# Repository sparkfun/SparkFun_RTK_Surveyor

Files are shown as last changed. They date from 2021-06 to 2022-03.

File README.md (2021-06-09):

SparkFun RTK Surveyor - Hardware
===========================================================

SparkFun RTK Surveyor (https://www.sparkfun.com/products/17369)

[*SparkFun RTK Surveyor (SPX-17369)*](https://www.sparkfun.com/products/17369)

The SparkFun RTK Surveyor is an easy to use GNSS receiver for centimeter-level positioning. Perfect for surveying, this preprogrammed device can also be used for autonomous driving, navigation, asset tracking and any other application where there is a clear view of the sky. The RTK Surveyor can also be used as a base station. With the flick of a switch, two RTK Surveyors can be used to create an RTK system capable of 14mm horizontal positional accuracy. The built-in Bluetooth connection via an ESP32 WROOM enables the user to use the RTK Surveyor with their choice of GIS application on a phone or tablet. The built in battery allows field use for up to four hours and is compatible with common USB battery banks.

This repo houses the hardware for the product including the PCB design, enclosure, and graphic overlay. The firmware for the RTK Surveyor (and other SparkFun RTK products) can be found [here](https://github.com/sparkfun/SparkFun_RTK_Firmware).

SparkFun labored with love to create this product. Feel like supporting open source hardware? 
[Buy a product](https://www.sparkfun.com/products/17369) from SparkFun!

Repository Contents
-------------------

* **/Documents** - Documentation on hardware and 3D files for the enclosure
* **/Enclosure** - gcode for enclosure milling
* **/Graphics** - Bitmaps for display (not currently implmented)
* **/Hardware** - Eagle files

Documentation
--------------

* **[Hookup Guide](https://learn.sparkfun.com/tutorials/sparkfun-rtk-surveyor-hookup-guide)** - Hookup guide for the SparkFun RTK Surveyor.

License Information
-------------------

This product is _**open source**_!

Various bits of the code have different licenses applied. Anything SparkFun wrote is beerware; if you see me (or any other SparkFun employee) at the local, and you've found our code helpful, please buy us a round!

Please use, reuse, and modify these files as you see fit. Please maintain attribution to SparkFun Electronics and release anything derivative under the same license.

Distributed as-is; no warranty is given.

- Your friends at SparkFun.

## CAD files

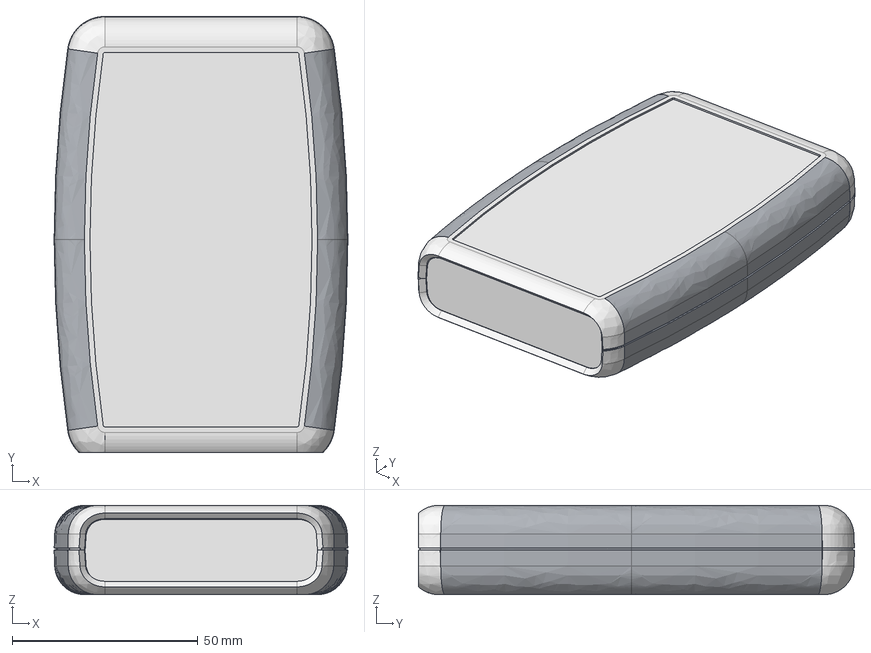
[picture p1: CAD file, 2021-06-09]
Documents/1553B-1.stp
79.0 x 117.2 x 24.0 mm
1553B TOP
1553B BOTTOM
1553B Front Panel
1553B TOP GRIP
1553B BOTTOM GRIP
1553B PCB

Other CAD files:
Documents/1553B-1.igs

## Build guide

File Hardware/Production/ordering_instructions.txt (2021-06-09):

panel size, 220x138mm
PCB thickness, 1.6mm
number of layers, 4
soldermask color, Red
silkscreen color, White
oz copper, 1oz
finish, HASL lead free
stencils, none
pcs per panel, 3
min trace width, 0.1778mm / 0.0070in
min drill size, 0.3048mm / 0.0120in
filename to layer stackup 1/2/3/4: GTL, GL2, GL3, GBL

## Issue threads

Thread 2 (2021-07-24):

RTK Surveor does not charge Lipo battery

artosaurus, 2021-07-24:
### RTK Surveor does not charge Lipo battery

RTK Surveyor does not charge its Lipo battery when connected to USB with wall adapter. The LED is totally off. When I switch power on the LED is red. I replaced new Lipo-battery and this does not help. It is possible to charge he battery of Surveyor using Turnigy charger so the battery is not malfunctioning.
To your information, I have RTK Surveyor and also RTK Express. I am using Surveoyr as Base and Express as Rover.
I bought Surveyor about a year ago and did not use it at all because I noticed that I need a second unit. Therefore, I bought RTK express during summer 2021 and now I started to use these together and noticed this battery cahrger problem in Surveyor.
I tested Surveyor using the battery from RTK Express but the same problem exist - the LED is off and does not charge the battery. My RTK Surveyor is damaged for some reason. I can use it only when it is connected to an external USB power bank.

### Your workbench
SparkFun RTK Surveyor v1.3-Jun  7 2021.
Bluetooth is working OK.
NTRIP is coming via radio or alternatively website RT2GO and Bluetooth.
Everything is powered by external USB because battery is empty. Surveyour does not charge the battery anymore. The LED is totally off when main power of Surveyor is off and USB is connected.

### Steps to reproduce
Tell us how to reproduce this issue. Please include a copy of your settings.txt file used on the unit.
[SFE_Surveyor_Settings.txt](https://github.com/sparkfun/SparkFun_RTK_Surveyor/files/6872461/SFE_Surveyor_Settings.txt)

### Expected behavior
LED should be blue and battery should charge

### Actual behavior
LED is off and battery does not charge.

nseidle, 2021-07-29:
Ah! Sorry for letting this sit for so many days. My apologies.

I believe we've got a return in the works for you. Correct me if not.

We found a jumper on the charge IC that was causing it to fail. We're working on updating the test procedure to catch this fault in the future.

I'm going to leave open until we confirm you're charging again.

artosaurus, 2021-07-31:
Dear Nathan

Thank you for your email.
So what should I do now? Can I fix this myself? Could you identify the
jumper so I can fix it?

Arto

to 29. heinäk. 2021 klo 18.34 Nathan Seidle ***@***.***)
kirjoitti:

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

nseidle, 2021-08-03:
Please contact me nathan at sparkfun and I'll get you connected with the right support folks. I don't recommend you attempt to fix it unless you are proficient at hot-air rework. We'll remove the IC, clean up the solder joints and re-mount the charger IC.

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

Closed 2021-08-03.

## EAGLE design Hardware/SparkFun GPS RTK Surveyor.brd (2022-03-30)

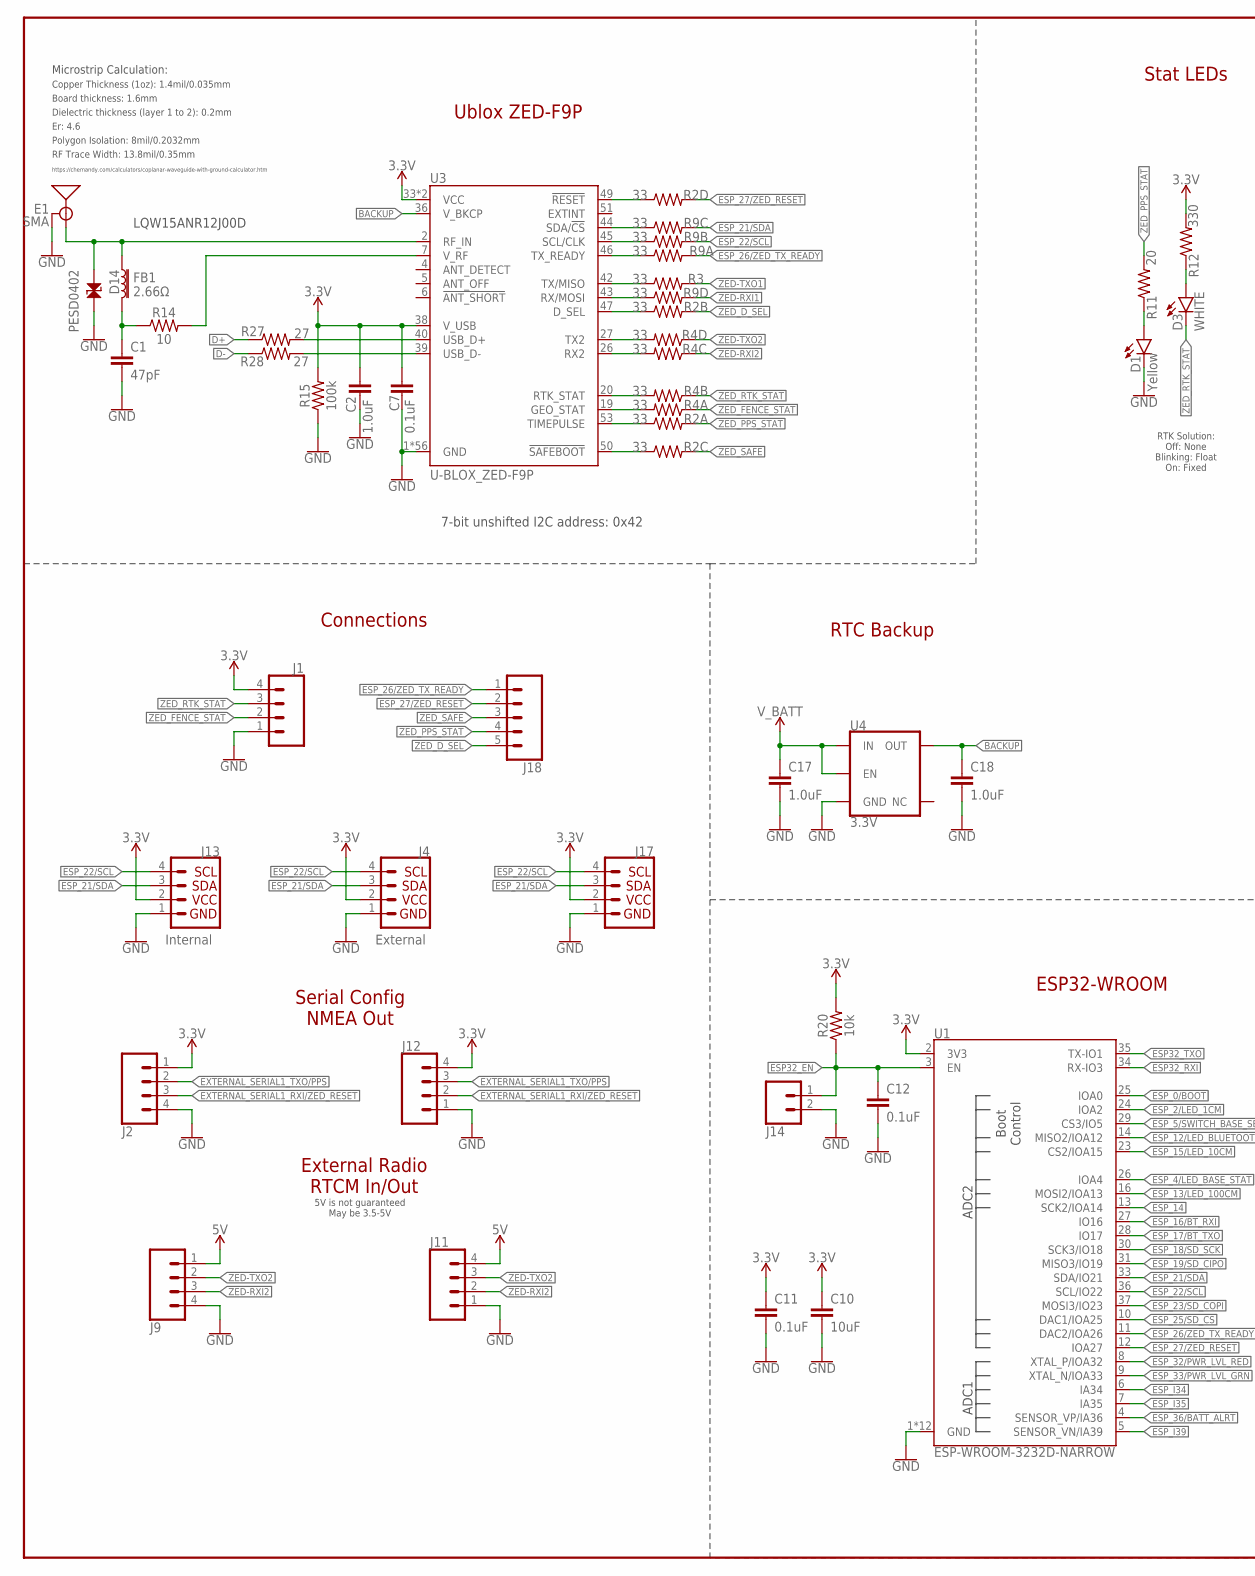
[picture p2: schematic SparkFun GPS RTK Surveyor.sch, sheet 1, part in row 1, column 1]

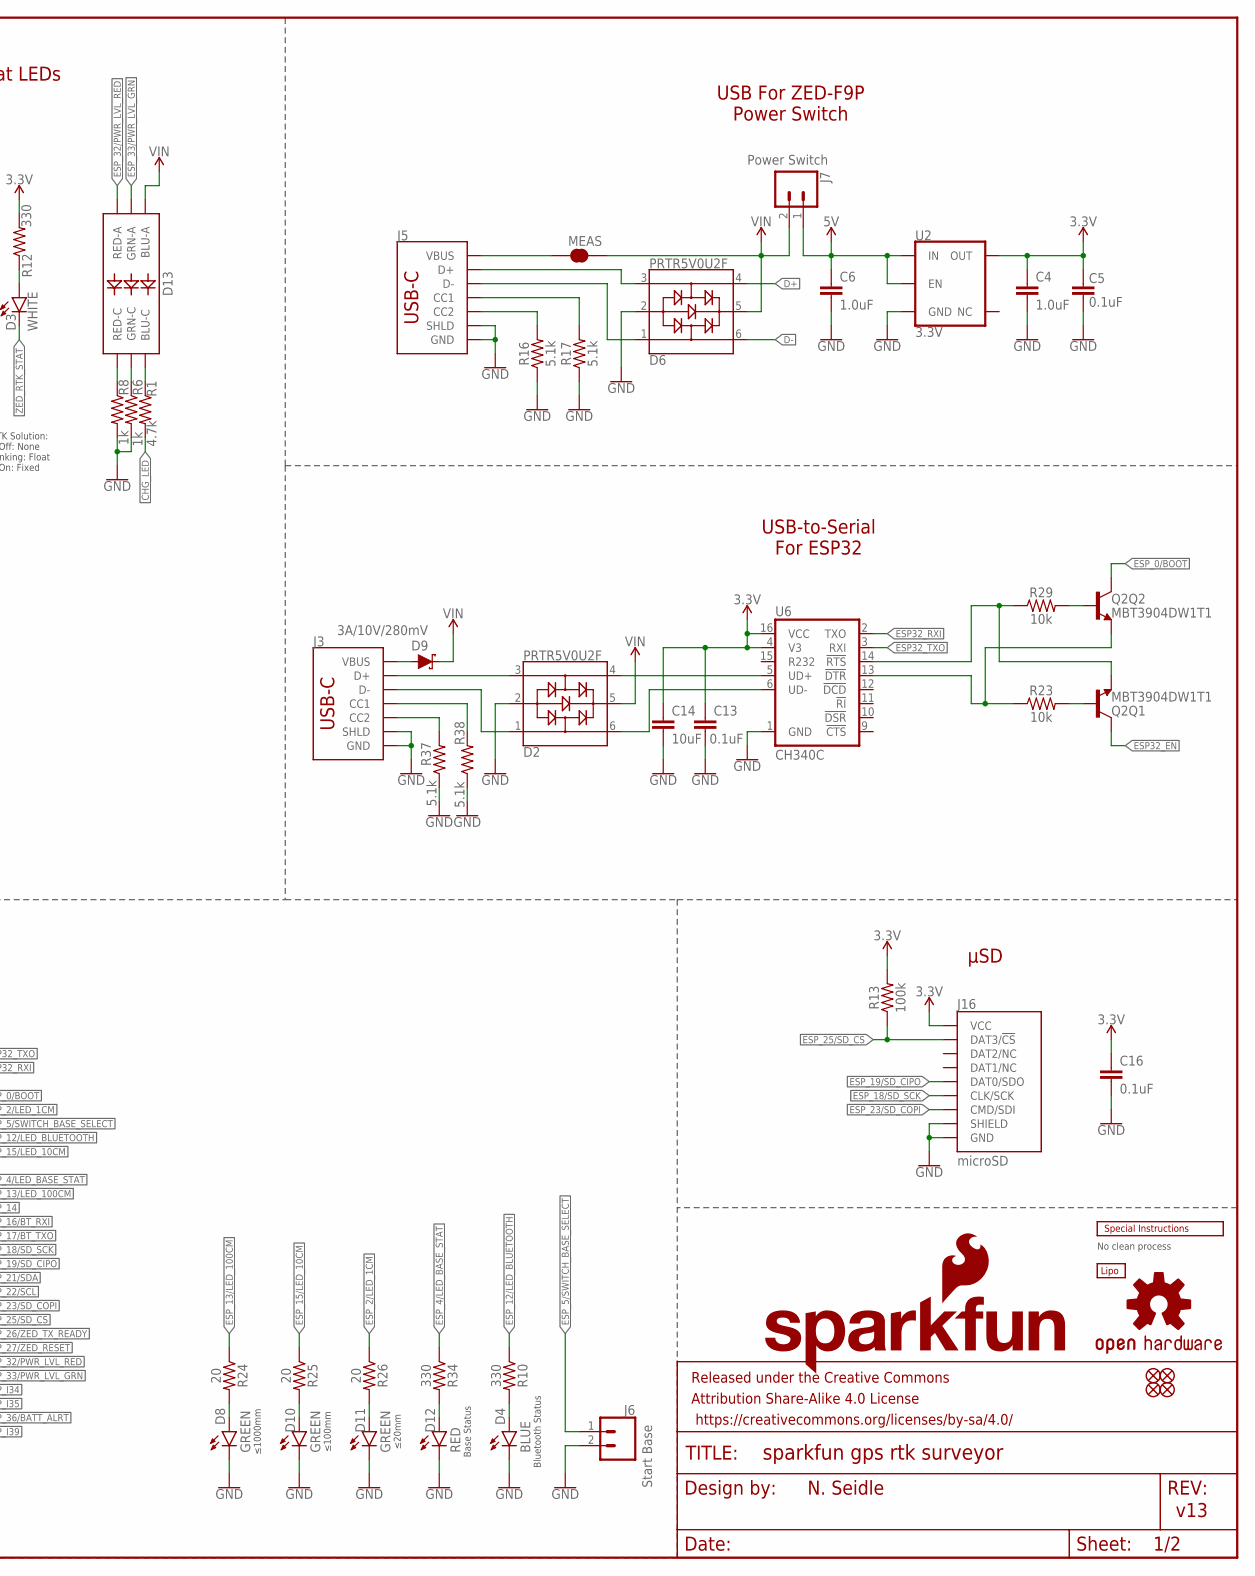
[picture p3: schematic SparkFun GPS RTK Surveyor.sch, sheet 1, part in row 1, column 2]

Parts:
BT1: LIPO-OUTLINE1000; LIPO-1000
C1: 47pF; 0402
C2, C4, C6, C17, C18: 1.0uF; 0603
C5, C7, C11, C12, C13, C16: 0.1uF; 0603
C10, C14: 10uF; 0603
D1: Yellow; LED-0603
D2, D6: PRTR5V0U2F; SOT886
D3: WHITE; LED-0603
D4: BLUE; LED-0603
D8, D10, D11: GREEN; LED-0603
D9: 3A/10V/280mV; SOD-323
D12: RED; LED-0603
D13: LED-RGBBRG; LED-TRICOLOR-5050
D14: PESD0402; 0402
E1: SMA; SMA-EDGE
FB1: 2.66Ω; 0402-TIGHT
FRAME2: FRAME-LEDGER; CREATIVE_COMMONS
J1, J11, J12: CONN_041X04_NO_SILK_NO_POP; 1X04_NO_SILK
J2, J9: CONN_04JST-SMD-LOCKING; JST-4-SMD-1.25MM-LOCKING
J3, J5: USB Female Type C Connector; USB-C-16P_4LAYER-PADS
J4: External; JST04_1MM_RA
J6: Start Base; JST-2-SMD
J7: Power Switch; JST-2-SMD
J13: Internal; JST04_1MM_RA
J14: CONN_021X02_NO_SILK; 1X02_NO_SILK
J16: microSD; MICRO-SD-SOCKET
J17: Qwiic Right Angle; 1X04_NO_SILK
J18: CONN_05NO_SILK; 1X05_NO_SILK
JP21, JP61, JP71, JP81: FIDUCIALUFIDUCIAL; FIDUCIAL-MICRO
LOGO1: OSHW-LOGOMINI; OSHW-LOGO-MINI
LOGO2: SFE_LOGO_NAME_FLAME.1_INCH; SFE_LOGO_NAME_FLAME_.1
MEAS: JUMPER-COMBO_2_NC_TRACE; COMBO-JUMPER_2_NC_TRACE
Q2: MBT3904DW1T1; SC70-6
R1: 4.7k; 0603
R2, R4, R9: 33; 1206_RA
R3: 33; 0603
R6, R8: 1k; 0603
R10, R12, R34: 330; 0603
R11, R24, R25, R26: 20; 0603
R13, R15: 100k; 0603
R14: 10; 0603
R16, R17, R37, R38: 5.1k; 0603
R20, R23, R29: 10k; 0603
R27, R28: 27; 0603
U1: ESP-WROOM-3232D-NARROW; ESP-WROOM-32D-NARROW
U2, U4: 3.3V; SOT23-5
U3: U-BLOX_ZED-F9P; ZED-F9P
U6: CH340C; SO016
U$2: SPECIAL_INSTRUCTIONS-ORDERING; ORDERING_INSTRUCTIONS

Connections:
3.3V: C2.1, C4.1, C5.2, C7.2, C10.1, C11.1, C13.1, C14.1, C16.1, J1.4, J2.1, J4.2, J12.4, J13.2, J16.VCC, J17.2, R12.2, R13.2, R15.2, R20.2, U1.2 (3V3), U2.5 (OUT), U3.33 (VCC), U3.34 (VCC), U3.38 (V_USB), U6.4 (V3), U6.16 (VCC)
5V: C6.1, J7.1 (2), J9.1, J11.4, U2.1 (IN), U2.3 (EN)
ANT_VCC: C1.1, FB1.2, R14.1
BACKUP: C18.1, U3.36 (V_BKCP), U4.5 (OUT)
CC1: J5.A5 (CC1), R17.2
CC2: J5.B5 (CC2), R16.2
CC3: J3.B5 (CC2), R37.2
CC4: J3.A5 (CC1), R38.2
CHG_LED: R1.2; also elsewhere on the board
D+: D6.4, R27.1
D+1: D2.4, U6.5 (UD+)
D-: D6.6, R28.1
D-1: D2.6, U6.6 (UD-)
ESP32_!DTR: Q2.1 (E), R23.1, U6.13 (!DTR)
ESP32_!RTS: Q2.4 (E), R29.1, U6.14 (!RTS)
ESP32_EN: C12.1, J14.1, Q2.3 (C), R20.1, U1.3 (EN)
ESP32_RXI: U1.34 (RX-IO3), U6.2 (TXO)
ESP32_TXO: U1.35 (TX-IO1), U6.3 (RXI)
ESP_0/BOOT: Q2.6 (C), U1.25 (IOA0)
ESP_2/LED_1CM: R26.1, U1.24 (IOA2)
ESP_4/LED_BASE_STAT: R34.1, U1.26 (IOA4)
ESP_5/SWITCH_BASE_SELECT: J6.1 (2), U1.29 (CS3/IO5)
ESP_12/LED_BLUETOOTH: R10.1, U1.14 (MISO2/IOA12)
ESP_13/LED_100CM: R24.1, U1.16 (MOSI2/IOA13)
ESP_14: U1.13 (SCK2/IOA14)
ESP_15/LED_10CM: R25.1, U1.23 (CS2/IOA15)
ESP_16/BT_RXI: U1.27 (IO16); also elsewhere on the board
ESP_17/BT_TXO: U1.28 (IO17); also elsewhere on the board
ESP_18/SD_SCK: J16.SCLK (CLK/SCK), U1.30 (SCK3/IO18)
ESP_19/SD_CIPO: J16.DO/DAT0 (DAT0/SDO), U1.31 (MISO3/IO19)
ESP_21/SDA: J4.3, J13.3, J17.3, R9.P6 (2), U1.33 (SDA/IO21); also elsewhere on the board
ESP_22/SCL: J4.4, J13.4, J17.4, R9.P7 (2), U1.36 (SCL/IO22); also elsewhere on the board
ESP_23/SD_COPI: J16.DI/CMD (CMD/SDI), U1.37 (MOSI3/IO23)
ESP_25/SD_!CS!: J16.CS/DAT3 (DAT3/!CS!), R13.1, U1.10 (DAC1/IOA25)
ESP_26/ZED_TX_READY: J18.1, R9.P8 (2), U1.11 (DAC2/IOA26)
ESP_26/ZED_TX_READY_LV: R9.P1 (1), U3.46 (TX_READY)
ESP_27/ZED_!RESET!: J18.2, R2.P5 (2), U1.12 (IOA27); also elsewhere on the board
ESP_27/ZED_!RESET!_LV: R2.P4 (1), U3.49 (!RESET!)
ESP_32/PWR_LVL_RED: D13.5 (RED-A), U1.8 (XTAL_P/IOA32)
ESP_33/PWR_LVL_GRN: D13.4 (GRN-A), U1.9 (XTAL_N/IOA33)
ESP_36/BATT_ALRT: U1.4 (SENSOR_VP/IA36); also elsewhere on the board
ESP_D1+: D2.3, J3.A6 (D+), J3.B6 (D+)
ESP_D1-: D2.1, J3.A7 (D-), J3.B7 (D-)
ESP_I34: U1.6 (IA34)
ESP_I35: U1.7 (IA35)
ESP_I39: U1.5 (SENSOR_VN/IA39)
EXTERNAL_SERIAL1_RXI/ZED_!RESET!: J2.3, J12.2; also elsewhere on the board
EXTERNAL_SERIAL1_TXO/PPS: J2.2, J12.3; also elsewhere on the board
FENCE_LV: R4.P8 (2), U3.19 (GEO_STAT)
GND: C1.2, C2.2, C4.2, C5.1, C6.2, C7.1, C10.2, C11.2, C12.2, C13.2, C14.2, C16.2, C17.2, C18.2, D1.C, D2.2, D4.C, D6.2, D8.C, D10.C, D11.C, D12.C, D14.2, E1.GND@0 (GND), E1.GND@1 (GND), E1.GND@2 (GND), E1.GND@3 (GND), J1.1, J2.4, J3.GND, J3.GND2 (GND), J3.SHLD1 (SHLD), J3.SHLD2 (SHLD), J3.SHLD3 (SHLD), J3.SHLD4 (SHLD), J4.1, J5.GND, J5.GND2 (GND), J5.SHLD1 (SHLD), J5.SHLD2 (SHLD), J5.SHLD3 (SHLD), J5.SHLD4 (SHLD), J6.2 (1), J9.4, J11.1, J12.1, J13.1, J14.2, J16.CD1 (SHIELD), J16.GND, J16.GND1 (GND), J16.GND3 (GND), J17.1, R6.2, R8.2, R15.1, R16.1, R17.1, R37.1, R38.1, U1.1 (GND), U1.15 (GND), U1.38 (GND), U1.GND1 (GND), U1.GNDT1 (GND), U1.GNDT2 (GND), U1.GNDT3 (GND), U1.GNDT4 (GND), U1.GNDT5 (GND), U1.GNDT6 (GND), U1.GNDT7 (GND), U1.GNDT8 (GND), U2.2 (GND), U3.1 (GND), U3.3 (GND), U3.12 (GND), U3.14 (GND), U3.32 (GND), U3.37 (GND), U3.41 (GND), U3.48 (GND), U3.55 (GND), U3.56 (GND), U3.57 (GND), U3.58 (GND), U3.59 (GND), U3.60 (GND), U3.61 (GND), U3.62 (GND), U3.63 (GND), U3.64 (GND), U3.65 (GND), U3.66 (GND), U3.67 (GND), U3.68 (GND), U3.69 (GND), U3.70 (GND), U3.71 (GND), U3.72 (GND), U3.73 (GND), U3.74 (GND), U3.75 (GND), U3.76 (GND), U3.77 (GND), U3.78 (GND), U3.79 (GND), U3.80 (GND), U3.81 (GND), U3.82 (GND), U3.83 (GND), U3.84 (GND), U3.85 (GND), U3.86 (GND), U3.87 (GND), U3.88 (GND), U3.89 (GND), U3.90 (GND), U3.91 (GND), U3.92 (GND), U3.93 (GND), U3.94 (GND), U3.95 (GND), U3.96 (GND), U3.97 (GND), U3.98 (GND), U3.99 (GND), U3.100 (GND), U3.101 (GND), U3.102 (GND), U4.2 (GND), U6.1 (GND); also elsewhere on the board
GPS_ANT1: D14.1, E1.SIG (SIGNAL), FB1.1, U3.2 (RF_IN)
unnamed: D3.A, R12.1
unnamed: D1.A, R11.1
unnamed: D4.A, R10.2
unnamed: J5.VBUS1 (VBUS), J5.VBUS2 (VBUS), MEAS.1, MEAS.3 (1)
unnamed: D13.1 (BLU-C), R1.1
unnamed: D13.3 (GRN-C), R6.1
unnamed: D13.2 (RED-C), R8.1
unnamed: R27.2, U3.40 (USB_D+)
unnamed: R28.2, U3.39 (USB_D-)
unnamed: R14.2, U3.7 (V_RF)
unnamed: Q2.5 (B), R23.2
unnamed: Q2.2 (B), R29.2
unnamed: D8.A, R24.2
unnamed: D10.A, R25.2
unnamed: D11.A, R26.2
unnamed: D12.A, R34.2
unnamed: D9.A, J3.VBUS1 (VBUS), J3.VBUS2 (VBUS)
PPS: R2.P1 (1), U3.53 (TIMEPULSE)
RTK_LV: R4.P7 (2), U3.20 (RTK_STAT)
RX2_LV: R4.P6 (2), U3.26 (RX2)
RXLV: R9.P4 (1), U3.43 (RX/MOSI)
SCL_LV: R9.P2 (1), U3.45 (SCL/CLK)
SDA_LV: R9.P3 (1), U3.44 (SDA/!CS!)
TX2_LV: R4.P5 (2), U3.27 (TX2)
TXLV: R3.1, U3.42 (TX/MISO)
UNP_D+: D6.3, J5.A6 (D+), J5.B6 (D+)
UNP_D-: D6.1, J5.A7 (D-), J5.B7 (D-)
VIN: D2.5, D6.5, D9.C, D13.6 (BLU-A), J7.2 (1), MEAS.2, MEAS.4 (2); also elsewhere on the board
V_BATT: C17.1, U4.1 (IN), U4.3 (EN); also elsewhere on the board
ZED-RXI1: R9.P5 (2); also elsewhere on the board
ZED-RXI2: J9.3, J11.2, R4.P3 (1); also elsewhere on the board
ZED-TXO1: R3.2; also elsewhere on the board
ZED-TXO2: J9.2, J11.3, R4.P4 (1); also elsewhere on the board
ZED_!SAFE!: J18.3, R2.P6 (2)
ZED_!SAFE!_LV: R2.P3 (1), U3.50 (!SAFEBOOT!)
ZED_D_SEL: J18.5, R2.P7 (2)
ZED_D_SEL_LV: R2.P2 (1), U3.47 (D_SEL)
ZED_FENCE_STAT: J1.2, R4.P1 (1)
ZED_PPS_STAT: J18.4, R2.P8 (2), R11.2; also elsewhere on the board
ZED_RTK_STAT: D3.C, J1.3, R4.P2 (1)

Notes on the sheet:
v13
7-bit unshifted I2C address: 0x42
Ublox ZED-F9P
RTC Backup
Stat LEDs
LQW15ANR12J00D
Board thickness: 1.6mm
Er: 4.6
Copper Thickness (1oz): 1.4mil/0.035mm
RF Trace Width: 13.8mil/0.35mm
Polygon Isolation: 8mil/0.2032mm
No clean process
Dielectric thickness (layer 1 to 2): 0.2mm
https://chemandy.com/calculators/coplanar-waveguide-with-ground-calculator.htm
Microstrip Calculation:
Connections
External Radio RTCM In/Out
Serial Config NMEA Out
Base Status
≤1000mm
≤100mm
≤20mm
ESP32-WROOM
USB-to-Serial For ESP32
RTK Solution: Off: None Blinking: Float On: Fixed
Bluetooth Status
μSD
5V is not guaranteed May be 3.5-5V
USB For ZED-F9P Power Switch
N. Seidle

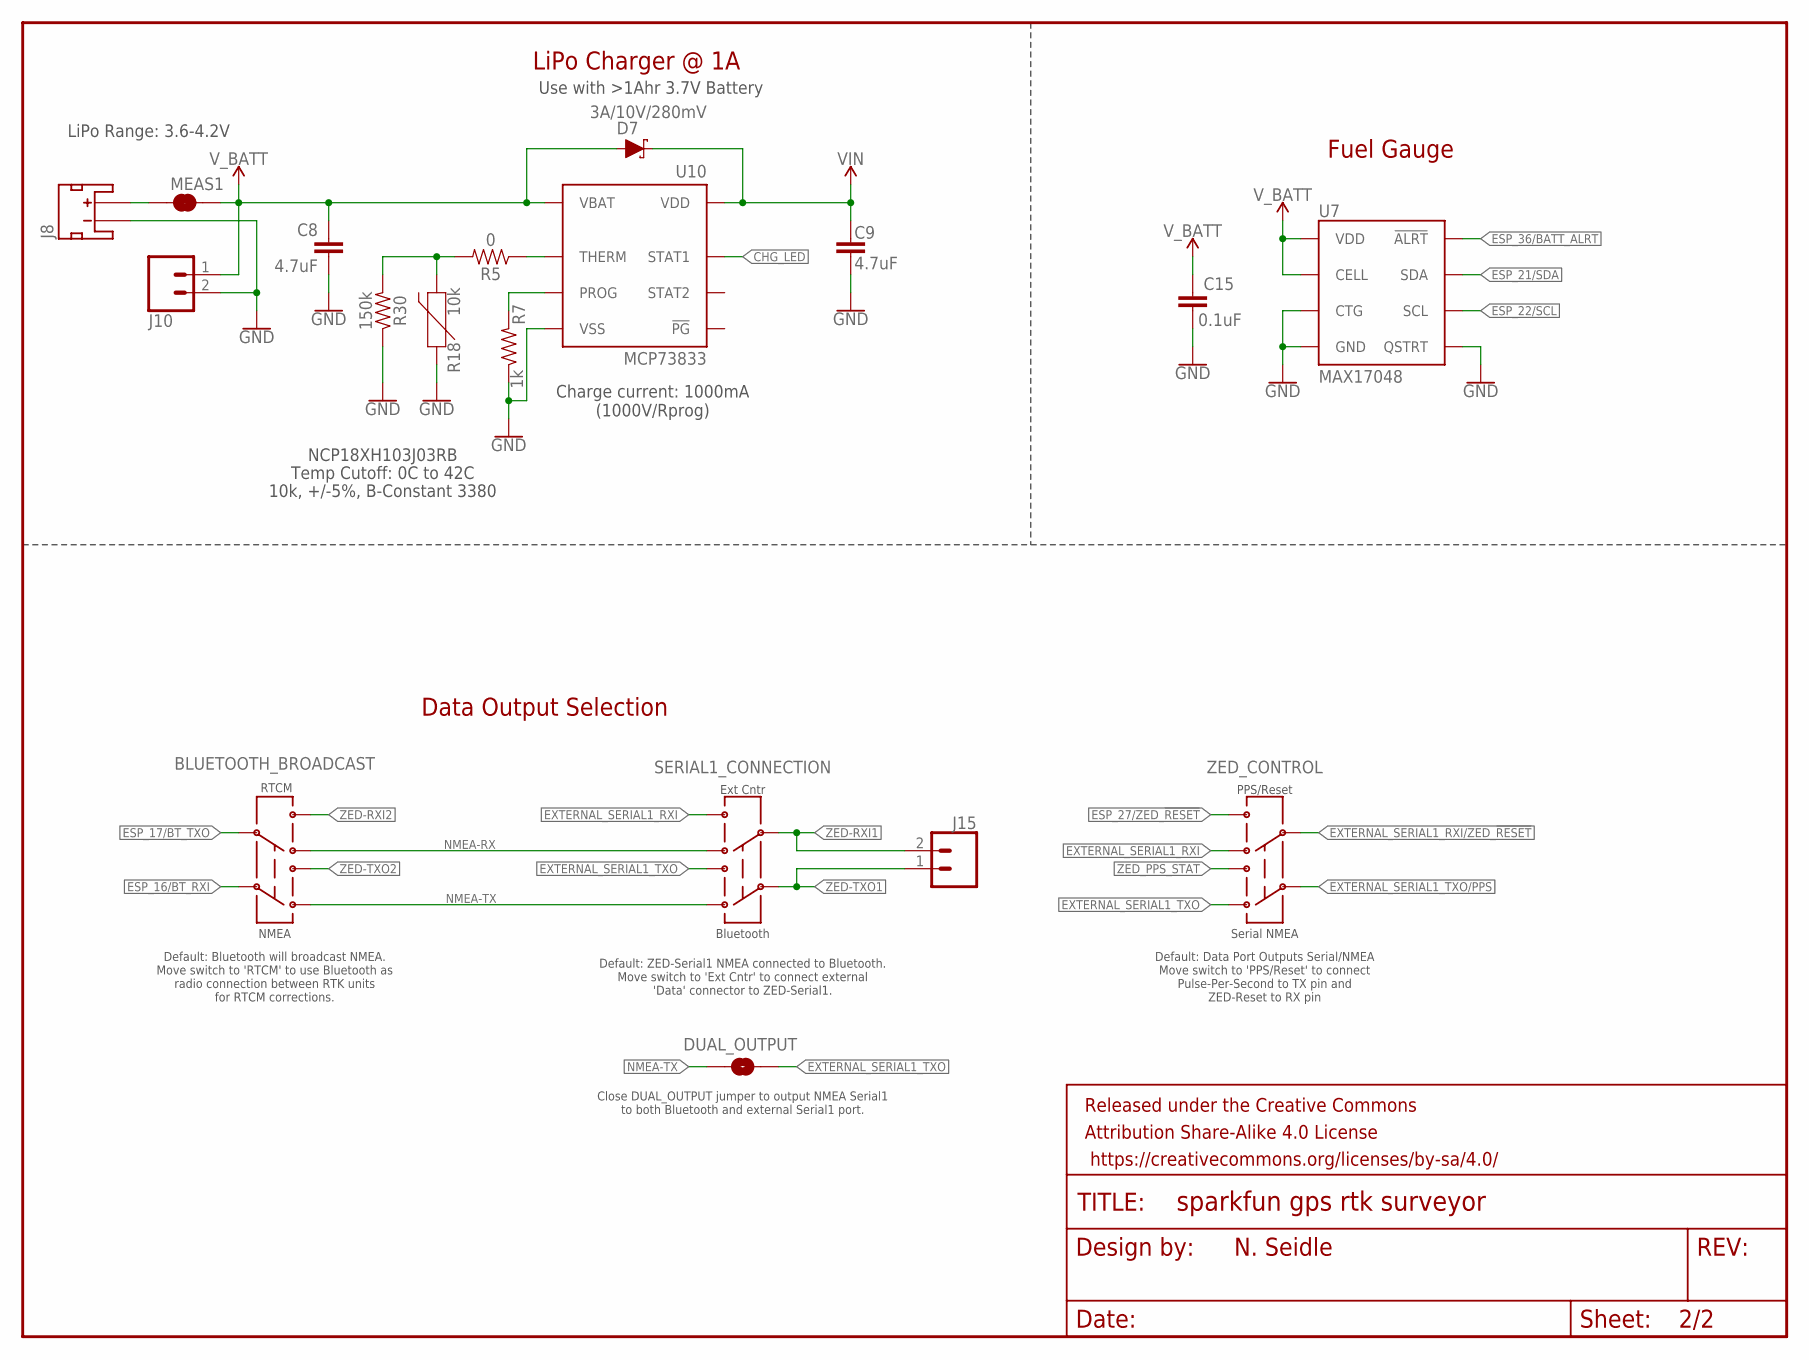
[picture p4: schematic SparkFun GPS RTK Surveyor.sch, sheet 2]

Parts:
BLUETOOTH_BROADCAST: SWITCH-DPDT-SMD-AYZ0202; SWITCH_DPDT_SMD_AYZ0202
C8, C9: 4.7uF; 0603
C15: 0.1uF; 0603
D7: 3A/10V/280mV; SOD-323
DUAL_OUTPUT: JUMPER-SMT_2_NO_SILK; SMT-JUMPER_2_NO_SILK
FRAME1: FRAME-LETTERNO_PACKAGE; DUMMY
J8: JST_2MM_MALE; JST-2-SMD
J10, J15: CONN_021X02_NO_SILK; 1X02_NO_SILK
MEAS1: JUMPER-COMBO_2_NC_TRACE; COMBO-JUMPER_2_NC_TRACE
R5: 0; 0603
R7: 1k; 0603
R18: 10k; 0603
R30: 150k; 0603
SERIAL1_CONNECTION: SWITCH-DPDT-SMD-AYZ0202; SWITCH_DPDT_SMD_AYZ0202
U7: MAX17048; DFN-8
U10: MCP73833; DFN-10
ZED_CONTROL: SWITCH-DPDT-SMD-AYZ0202; SWITCH_DPDT_SMD_AYZ0202

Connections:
CHG_LED: U10.3 (STAT1); also elsewhere on the board
CHG_THERM1: R5.2, R18.2, R30.2
ESP_16/BT_RXI: BLUETOOTH_BROADCAST.2; also elsewhere on the board
ESP_17/BT_TXO: BLUETOOTH_BROADCAST.5; also elsewhere on the board
ESP_21/SDA: U7.8 (SDA); also elsewhere on the board
ESP_22/SCL: U7.7 (SCL); also elsewhere on the board
ESP_27/ZED_!RESET!: ZED_CONTROL.4; also elsewhere on the board
ESP_36/BATT_ALRT: U7.5 (!ALRT); also elsewhere on the board
EXTERNAL_SERIAL1_RXI: SERIAL1_CONNECTION.4, ZED_CONTROL.6
EXTERNAL_SERIAL1_RXI/ZED_!RESET!: ZED_CONTROL.5; also elsewhere on the board
EXTERNAL_SERIAL1_TXO: DUAL_OUTPUT.2, SERIAL1_CONNECTION.1, ZED_CONTROL.3
EXTERNAL_SERIAL1_TXO/PPS: ZED_CONTROL.2; also elsewhere on the board
GND: C8.2, C9.2, C15.2, J8.1 (-), J10.2, R7.1, R18.1, R30.1, U7.1 (CTG), U7.4 (GND), U7.6 (QSTRT), U7.9 (GND), U10.5 (VSS), U10.11 (VSS); also elsewhere on the board
LIPO_RAW: J8.2 (+), MEAS1.1, MEAS1.3 (1)
unnamed: R5.1, U10.8 (THERM)
NMEA-RX: BLUETOOTH_BROADCAST.6, SERIAL1_CONNECTION.6
NMEA-TX: BLUETOOTH_BROADCAST.3, DUAL_OUTPUT.1, SERIAL1_CONNECTION.3
PROG1: R7.2, U10.6 (PROG)
VIN: C9.1, D7.C, U10.1 (VDD), U10.2 (VDD); also elsewhere on the board
V_BATT: C8.1, C15.1, D7.A, J10.1, MEAS1.2, MEAS1.4 (2), U7.2 (CELL), U7.3 (VDD), U10.9 (VBAT), U10.10 (VBAT); also elsewhere on the board
ZED-RXI1: J15.2, SERIAL1_CONNECTION.5; also elsewhere on the board
ZED-RXI2: BLUETOOTH_BROADCAST.4; also elsewhere on the board
ZED-TXO1: J15.1, SERIAL1_CONNECTION.2; also elsewhere on the board
ZED-TXO2: BLUETOOTH_BROADCAST.1; also elsewhere on the board
ZED_PPS_STAT: ZED_CONTROL.1; also elsewhere on the board

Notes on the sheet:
LiPo Range: 3.6-4.2V
Charge current: 1000mA (1000V/Rprog)
Use with >1Ahr 3.7V Battery
LiPo Charger @ 1A
NCP18XH103J03RB
10k, +/-5%, B-Constant 3380
Temp Cutoff: 0C to 42C
Fuel Gauge
Default: Bluetooth will broadcast NMEA. Move switch to 'RTCM' to use Bluetooth as radio connection between RTK units for RTCM corrections.
Default: ZED-Serial1 NMEA connected to Bluetooth. Move switch to 'Ext Cntr' to connect external 'Data' connector to ZED-Serial1.
Close DUAL_OUTPUT jumper to output NMEA Serial1 to both Bluetooth and external Serial1 port.
Data Output Selection
RTCM
NMEA
Ext Cntr
Bluetooth
N. Seidle
Default: Data Port Outputs Serial/NMEA Move switch to 'PPS/Reset' to connect Pulse-Per-Second to TX pin and ZED-Reset to RX pin
PPS/Reset
Serial NMEA

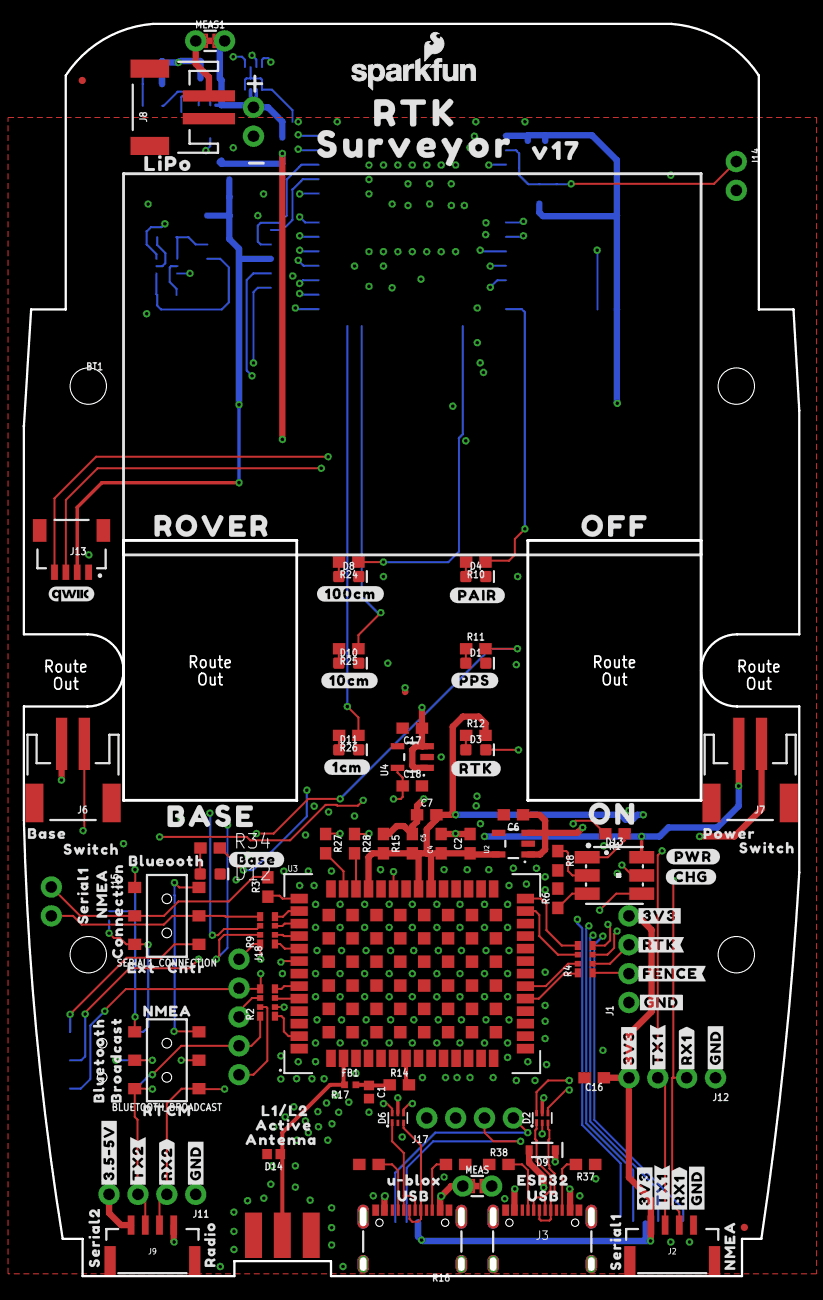
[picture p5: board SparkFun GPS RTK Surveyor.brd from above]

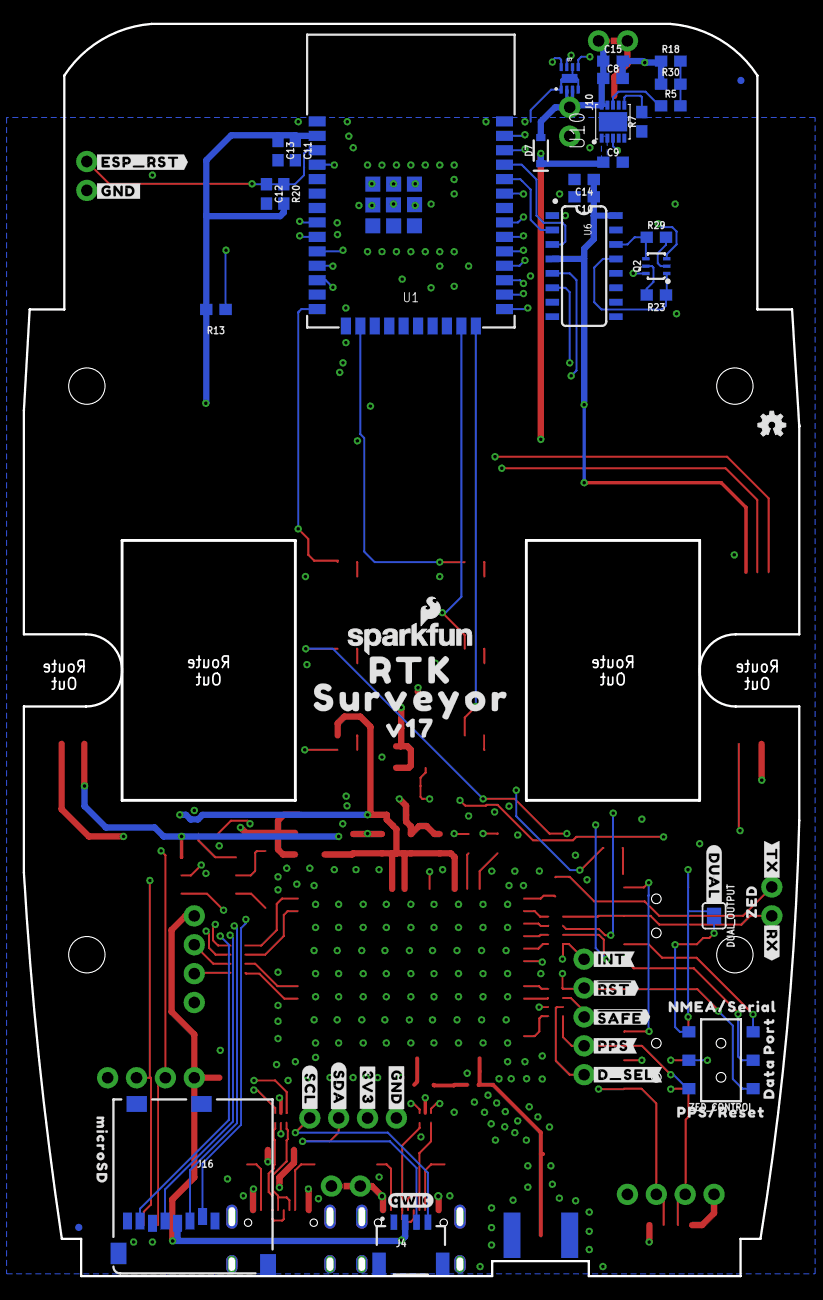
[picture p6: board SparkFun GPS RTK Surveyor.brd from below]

Board: 4 copper layers, 68.2 x 110.1 mm, 199 parts (55 on the bottom side), 95 nets.

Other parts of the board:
LOGO3: SFE_LOGO_NAME_FLAME.1_INCH; SFE_LOGO_NAME_FLAME_.1
U$1, U$38, U$48, U$82: #GND#0
U$3, U$34: ROCKER_SWITCH
U$4: #BASE#0
U$5, U$37, U$47: #3V3#0
U$6: ANTENNA0
U$7, U$74: RTK0
U$8: #CHG#0
U$9, U$71: _SURVEYOR3
U$10: #RTK#1
U$11: #PPS#0
U$12: #RTK#0
U$13, U$15, U$21, U$69, U$75, U$76, U$77, U$78: LIGHT_PIPE_3MM
U$14: #RX#2
U$16: ZED0
U$17: ##SAFE##5
U$18: ACTIVE0
U$19: L1#L21
U$20: #PAIR#0
U$22: BASE2
U$23: #3#5#5V#0
U$24: #PPS#1
U$25: #PWR#2
U$26: 1553DBK-ENCLOSURE
U$27: LIPO0
U$28: ##RST##4
U$29, U$63: SERIAL10
U$30, U$93: QWIIC_4MM
U$31: OFF1
U$32: #FENCE#3
U$33: #INT#0
U$35: U#BLOX0
U$36, U$66: USB1
U$39: #RX2#2
U$40: #TX2#1
U$41: BLUETOOTH2
U$42: ON0
U$43: SERIAL20
U$44: ROVER3
U$45, U$68: #RX1#2
U$46, U$65: #TX1#1
U$49, U$52: NMEA1
U$50: RADIO0
U$51: BROADCAST3
U$53: RTCM0
U$54: BASE0
U$55, U$57: SWITCH1
U$56: POWER0
U$58: BLUEOOTH3
U$59: CNTR1
U$60: #ESP_RST#0
U$61: EXT0
U$62: NMEA2
U$64: CONNECTION1
U$67: ESP320
U$70: #GND#2
U$72: #TX#1
U$73: #DUAL#0
U$79: #1CM#0
U$80: #10CM#1
U$81: #100CM#2
U$83: MICROSD0
U$84: #GND#1
U$85: #3V3#2
U$86: #SCL#1
U$87: #SDA#0
U$88: #D_SEL#0
U$89: DATA2
U$90: PORT3
U$91: PPS#RESET0
U$92: NMEA#SERIAL1
U$94, U$95: V170

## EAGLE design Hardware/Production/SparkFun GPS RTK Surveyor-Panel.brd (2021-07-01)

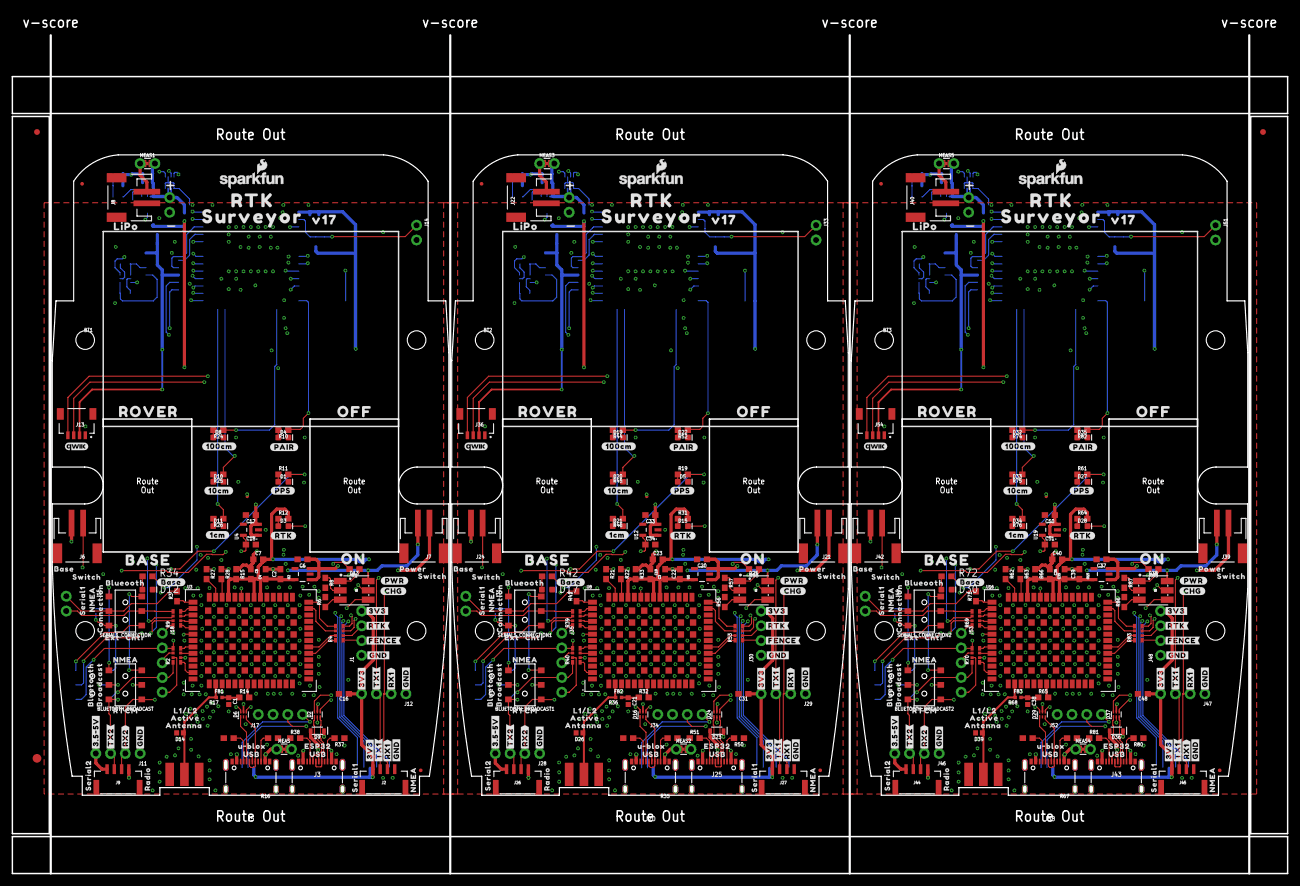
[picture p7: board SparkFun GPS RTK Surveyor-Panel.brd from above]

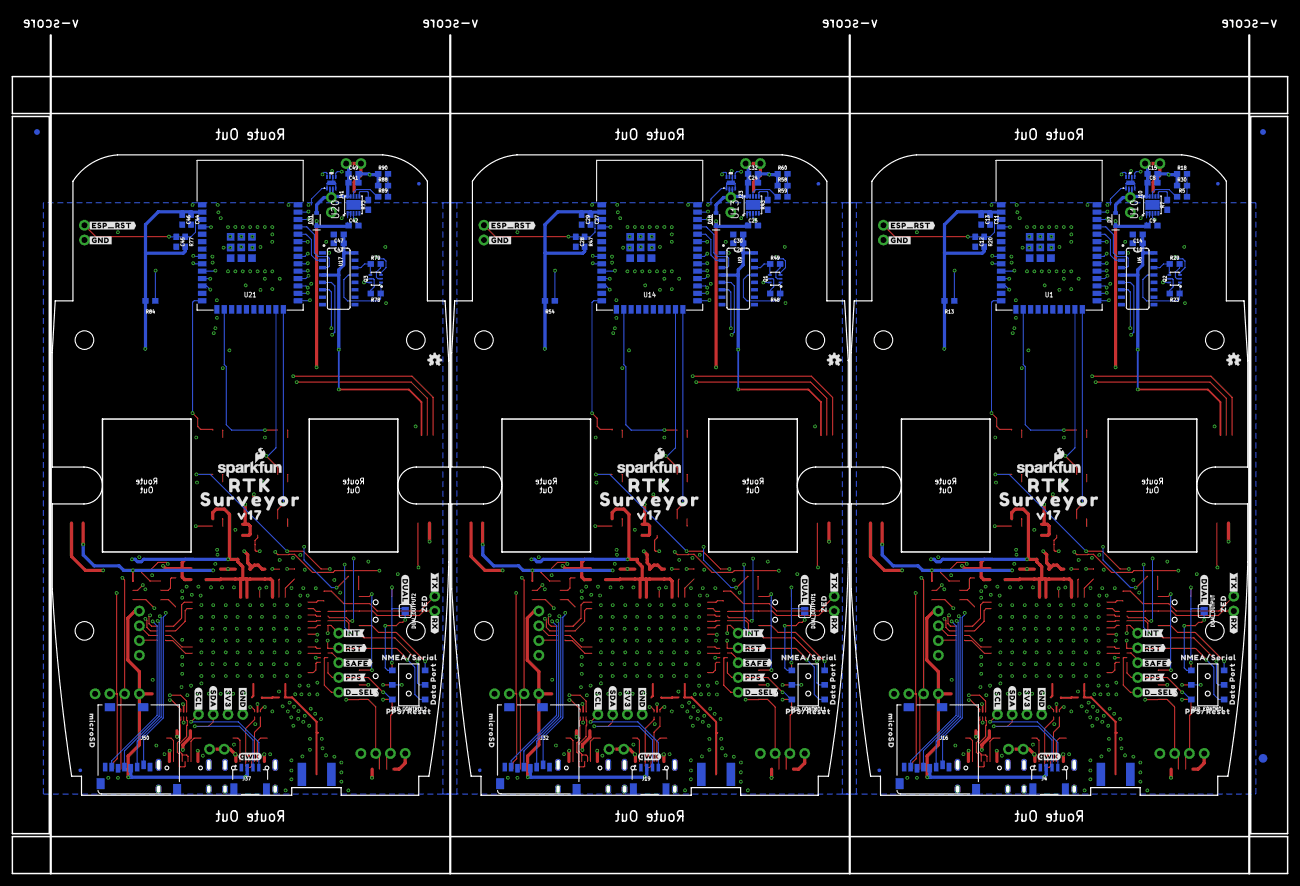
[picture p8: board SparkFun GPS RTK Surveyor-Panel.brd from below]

Board: 4 copper layers, 219.3 x 144.2 mm, 594 parts (168 on the bottom side), 285 nets.

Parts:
BLUETOOTH_BROADCAST, BLUETOOTH_BROADCAST1, BLUETOOTH_BROADCAST2: SWITCH_DPDT_SMD_AYZ0202
BT1, BT2, BT3: LIPO-OUTLINE1000; LIPO-1000
C1, C21, C38: 47pF; 0402
C2, C3, C4, C6, C17, C18, C20, C22, C33, C34, C35, C37, C39, C50, C51: 1.0uF; 0603
C5, C7, C11, C12, C13, C15, C16, C19, C23, C27, C28, C29, C31, C32, C36, C40, C44, C45, C46, C48, C49: 0.1uF; 0603
C8, C9, C24, C25, C41, C42: 4.7uF; 0603
C10, C14, C26, C30, C43, C47: 10uF; 0603
D1, D5, D27: Yellow; LED-0603
D2, D6, D16, D24, D29, D37: PRTR5V0U2F; SOT886
D3, D15, D28: WHITE; LED-0603
D4, D22, D35: BLUE; LED-0603
D7, D9, D18, D23, D31, D36: 3A/10V/280mV; SOD-323
D8, D10, D11, D19, D20, D21, D32, D33, D34: GREEN; LED-0603
D12, D17, D30: RED; LED-0603
D13, D25, D38: LED-TRICOLOR-5050
D14, D26, D39: PESD0402; 0402
DUAL_OUTPUT, DUAL_OUTPUT1, DUAL_OUTPUT2: SMT-JUMPER_2_NO_SILK
E1, E2, E3: SMA; SMA-EDGE
E$1, E$2, E$3, E$4: FIDUCIAL-1X2
E$5, E$6: FIDUCIAL-1.5X3
FB1, FB2, FB3: 2.66Ω; 0402-TIGHT
J1, J11, J12, J28, J29, J30, J46, J47, J48: 1X04_NO_SILK
J2, J9, J26, J27, J44, J45: JST-4-SMD-1.25MM-LOCKING
J3, J5, J20, J25, J38, J43: USB Female Type C Connector; USB-C-16P_4LAYER-PADS
J4, J19, J37: External; JST04_1MM_RA
J6, J24, J42: Start Base; JST-2-SMD
J7, J21, J39: Power Switch; JST-2-SMD
J8, J22, J40: JST-2-SMD
J10, J14, J15, J23, J31, J33, J41, J49, J51: 1X02_NO_SILK
J13, J36, J54: Internal; JST04_1MM_RA
J16, J32, J50: microSD; MICRO-SD-SOCKET
J17, J34, J52: Qwiic Right Angle; 1X04_NO_SILK
J18, J35, J53: 1X05_NO_SILK
JP1, JP2, JP3, JP4, JP5, JP6, JP7, JP8, JP21, JP61, JP71, JP81: FIDUCIALUFIDUCIAL; FIDUCIAL-MICRO
LOGO1, LOGO4, LOGO7: OSHW-LOGOMINI; OSHW-LOGO-MINI
LOGO2, LOGO3, LOGO5, LOGO6, LOGO8, LOGO9: SFE_LOGO_NAME_FLAME.1_INCH; SFE_LOGO_NAME_FLAME_.1
MEAS, MEAS1, MEAS2, MEAS3, MEAS4, MEAS5: COMBO-JUMPER_2_NC_TRACE
Q1, Q2, Q3: MBT3904DW1T1; SC70-6
R1, R55, R85: 4.7k; 0603
R2, R4, R9, R39, R40, R53, R69, R70, R83: 33; 1206_RA
R3, R41, R71: 33; 0603
R5, R59, R89: 0; 0603
R6, R7, R8, R43, R56, R57, R73, R86, R87: 1k; 0603
R10, R12, R31, R34, R42, R52, R64, R72, R82: 330; 0603
R11, R19, R24, R25, R26, R44, R45, R46, R61, R74, R75, R76: 20; 0603
R13, R15, R33, R54, R66, R84: 100k; 0603
R14, R32, R65: 10; 0603
R16, R17, R35, R36, R37, R38, R50, R51, R67, R68, R80, R81: 5.1k; 0603
R18, R20, R23, R29, R47, R48, R49, R60, R77, R78, R79, R90: 10k; 0603
R21, R22, R27, R28, R62, R63: 27; 0603
R30, R58, R88: 150k; 0603
SERIAL1_CONNECTION, SERIAL1_CONNECTION1, SERIAL1_CONNECTION2: SWITCH_DPDT_SMD_AYZ0202
U1, U14, U21: ESP-WROOM-3232D-NARROW; ESP-WROOM-32D-NARROW
U2, U4, U5, U12, U15, U19: 3.3V; SOT23-5
U3, U8, U16: U-BLOX_ZED-F9P; ZED-F9P
U6, U9, U17: CH340C; SO016
U7, U11, U18: MAX17048; DFN-8
U10, U13, U20: MCP73833; DFN-10
U$1, U$38, U$48, U$82, U$100, U$128, U$129, U$171, U$194, U$222, U$223, U$265: #GND#0
U$2, U$30, U$93, U$186, U$189, U$280: QWIIC_4MM
U$3, U$34, U$114, U$116, U$208, U$210: ROCKER_SWITCH
U$4, U$115, U$209: #BASE#0
U$5, U$37, U$47, U$99, U$127, U$168, U$193, U$221, U$262: #3V3#0
U$6, U$101, U$195: ANTENNA0
U$7, U$74, U$175, U$176, U$269, U$270: RTK0
U$8, U$108, U$202: #CHG#0
U$9, U$71, U$102, U$153, U$196, U$247: _SURVEYOR3
U$10, U$103, U$197: #RTK#1
U$11, U$152, U$246: #PPS#0
U$12, U$96, U$190: #RTK#0
U$13, U$15, U$21, U$69, U$75, U$76, U$77, U$78, U$117, U$118, U$151, U$158, U$159, U$160, U$161, U$162, U$211, U$212, U$245, U$252, U$253, U$254, U$255, U$256: LIGHT_PIPE_3MM
U$14, U$154, U$248: #RX#2
U$16, U$155, U$249: ZED0
U$17, U$133, U$227: ##SAFE##5
U$18, U$104, U$198: ACTIVE0
U$19, U$105, U$199: L1#L21
U$20, U$106, U$200: #PAIR#0
U$22, U$119, U$213: BASE2
U$23, U$140, U$234: #3#5#5V#0
U$24, U$97, U$191: #PPS#1
U$25, U$98, U$192: #PWR#2
U$26, U$107, U$201: 1553DBK-ENCLOSURE
U$27, U$109, U$203: LIPO0
U$28, U$132, U$226: ##RST##4
U$29, U$63, U$113, U$149, U$207, U$243: SERIAL10
U$31, U$120, U$214: OFF1
U$32, U$134, U$228: #FENCE#3
U$33, U$135, U$229: #INT#0
U$35, U$110, U$204: U#BLOX0
U$36, U$66, U$111, U$166, U$205, U$260: USB1
U$39, U$123, U$217: #RX2#2
U$40, U$124, U$218: #TX2#1
U$41, U$141, U$235: BLUETOOTH2
U$42, U$121, U$215: ON0
U$43, U$112, U$206: SERIAL20
U$44, U$122, U$216: ROVER3
U$45, U$68, U$125, U$170, U$219, U$264: #RX1#2
U$46, U$65, U$126, U$169, U$220, U$263: #TX1#1
U$49, U$52, U$130, U$143, U$224, U$237: NMEA1
U$50, U$131, U$225: RADIO0
U$51, U$142, U$236: BROADCAST3
U$53, U$144, U$238: RTCM0
U$54, U$136, U$230: BASE0
U$55, U$57, U$137, U$139, U$231, U$233: SWITCH1
U$56, U$138, U$232: POWER0
U$58, U$145, U$239: BLUEOOTH3
U$59, U$146, U$240: CNTR1
U$60, U$174, U$268: #ESP_RST#0
U$61, U$147, U$241: EXT0
U$62, U$148, U$242: NMEA2
U$64, U$150, U$244: CONNECTION1
U$67, U$167, U$261: ESP320
U$70, U$177, U$271: #GND#2
U$72, U$156, U$250: #TX#1
U$73, U$157, U$251: #DUAL#0
U$79, U$163, U$257: #1CM#0
U$80, U$164, U$258: #10CM#1
U$81, U$165, U$259: #100CM#2
U$83, U$172, U$266: MICROSD0
U$84, U$173, U$267: #GND#1
U$85, U$178, U$272: #3V3#2
U$86, U$179, U$273: #SCL#1
U$87, U$180, U$274: #SDA#0
U$88, U$181, U$275: #D_SEL#0
U$89, U$182, U$276: DATA2
U$90, U$183, U$277: PORT3
U$91, U$184, U$278: PPS#RESET0
U$92, U$185, U$279: NMEA#SERIAL1
U$94, U$95, U$187, U$188, U$281, U$282: V170
ZED_CONTROL, ZED_CONTROL1, ZED_CONTROL2: SWITCH_DPDT_SMD_AYZ0202

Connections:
3.3V: C2.1, C4.1, C5.2, C7.2, C10.1, C11.1, C13.1, C14.1, C16.1, J1.4, J2.1, J4.2, J12.4, J13.2, J16.VCC, J17.2, R12.2, R13.2, R15.2, R20.2, U1.2, U2.5, U3.33, U3.34, U3.38, U6.4, U6.16
3.3V1: C3.1, C19.2, C22.1, C23.2, C26.1, C27.1, C29.1, C30.1, C31.1, J19.2, J27.1, J29.4, J30.4, J32.VCC, J34.2, J36.2, R31.2, R33.2, R47.2, R54.2, U5.5, U8.33, U8.34, U8.38, U9.4, U9.16, U14.2
3.3V2: C35.1, C36.2, C39.1, C40.2, C43.1, C44.1, C46.1, C47.1, C48.1, J37.2, J45.1, J47.4, J48.4, J50.VCC, J52.2, J54.2, R64.2, R66.2, R77.2, R84.2, U15.5, U16.33, U16.34, U16.38, U17.4, U17.16, U21.2
5V: C6.1, J7.1, J9.1, J11.4, U2.1, U2.3
5V1: C20.1, J21.1, J26.1, J28.4, U5.1, U5.3
5V2: C37.1, J39.1, J44.1, J46.4, U15.1, U15.3
ANT_VCC: C1.1, FB1.2, R14.1
ANT_VCC1: C21.1, FB2.2, R32.1
ANT_VCC2: C38.1, FB3.2, R65.1
BACKUP: C18.1, U3.36, U4.5
BACKUP1: C34.1, U8.36, U12.5
BACKUP2: C51.1, U16.36, U19.5
CC1: J5.A5, R17.2
CC2: J5.B5, R16.2
CC3: J3.B5, R37.2
CC4: J3.A5, R38.2
CC5: J20.A5, R36.2
CC6: J20.B5, R35.2
CC7: J25.B5, R50.2
CC8: J25.A5, R51.2
CC9: J38.A5, R68.2
CC10: J38.B5, R67.2
CC11: J43.B5, R80.2
CC12: J43.A5, R81.2
CHG_LED: R1.2, U10.3
CHG_LED1: R55.2, U13.3
CHG_LED2: R85.2, U20.3
CHG_THERM1: R5.2, R18.2, R30.2
CHG_THERM2: R58.2, R59.2, R60.2
CHG_THERM3: R88.2, R89.2, R90.2
D+: D6.4, R27.1
D+1: D2.4, U6.5
D+2: D16.4, R21.1
D+3: D24.4, U9.5
D+4: D29.4, R62.1
D+5: D37.4, U17.5
D-: D6.6, R28.1
D-1: D2.6, U6.6
D-2: D16.6, R22.1
D-3: D24.6, U9.6
D-4: D29.6, R63.1
D-5: D37.6, U17.6
ESP32_!DTR: Q2.1, R23.1, U6.13
ESP32_!DTR1: Q1.1, R48.1, U9.13
ESP32_!DTR2: Q3.1, R78.1, U17.13
ESP32_!RTS: Q2.4, R29.1, U6.14
ESP32_!RTS1: Q1.4, R49.1, U9.14
ESP32_!RTS2: Q3.4, R79.1, U17.14
ESP32_EN: C12.1, J14.1, Q2.3, R20.1, U1.3
ESP32_EN1: C28.1, J33.1, Q1.3, R47.1, U14.3
ESP32_EN2: C45.1, J51.1, Q3.3, R77.1, U21.3
ESP32_RXI: U1.34, U6.2
ESP32_RXI1: U9.2, U14.34
ESP32_RXI2: U17.2, U21.34
ESP32_TXO: U1.35, U6.3
ESP32_TXO1: U9.3, U14.35
ESP32_TXO2: U17.3, U21.35
ESP_0/BOOT: Q2.6, U1.25
ESP_0/BOOT1: Q1.6, U14.25
ESP_0/BOOT2: Q3.6, U21.25
ESP_2/LED_1CM: R26.1, U1.24
ESP_2/LED_1CM1: R46.1, U14.24
ESP_2/LED_1CM2: R76.1, U21.24
ESP_4/LED_BASE_STAT: R34.1, U1.26
ESP_4/LED_BASE_STAT1: R42.1, U14.26
ESP_4/LED_BASE_STAT2: R72.1, U21.26
ESP_5/SWITCH_BASE_SELECT: J6.1, U1.29
ESP_5/SWITCH_BASE_SELECT1: J24.1, U14.29
ESP_5/SWITCH_BASE_SELECT2: J42.1, U21.29
ESP_12/LED_BLUETOOTH: R10.1, U1.14
ESP_12/LED_BLUETOOTH1: R52.1, U14.14
ESP_12/LED_BLUETOOTH2: R82.1, U21.14
ESP_13/LED_100CM: R24.1, U1.16
ESP_13/LED_100CM1: R44.1, U14.16
ESP_13/LED_100CM2: R74.1, U21.16
ESP_15/LED_10CM: R25.1, U1.23
ESP_15/LED_10CM1: R45.1, U14.23
ESP_15/LED_10CM2: R75.1, U21.23
ESP_16/BT_RXI: BLUETOOTH_BROADCAST.2, U1.27
ESP_16/BT_RXI1: BLUETOOTH_BROADCAST1.2, U14.27
ESP_16/BT_RXI2: BLUETOOTH_BROADCAST2.2, U21.27
ESP_17/BT_TXO: BLUETOOTH_BROADCAST.5, U1.28
ESP_17/BT_TXO1: BLUETOOTH_BROADCAST1.5, U14.28
ESP_17/BT_TXO2: BLUETOOTH_BROADCAST2.5, U21.28
ESP_18/SD_SCK: J16.SCLK, U1.30
ESP_18/SD_SCK1: J32.SCLK, U14.30
ESP_18/SD_SCK2: J50.SCLK, U21.30
ESP_19/SD_CIPO: J16.DO/DAT0, U1.31
ESP_19/SD_CIPO1: J32.DO/DAT0, U14.31
ESP_19/SD_CIPO2: J50.DO/DAT0, U21.31
ESP_21/SDA: J4.3, J13.3, J17.3, R9.P6, U1.33, U7.8
ESP_21/SDA1: J19.3, J34.3, J36.3, R39.P6, U11.8, U14.33
ESP_21/SDA2: J37.3, J52.3, J54.3, R69.P6, U18.8, U21.33
ESP_22/SCL: J4.4, J13.4, J17.4, R9.P7, U1.36, U7.7
ESP_22/SCL1: J19.4, J34.4, J36.4, R39.P7, U11.7, U14.36
ESP_22/SCL2: J37.4, J52.4, J54.4, R69.P7, U18.7, U21.36
ESP_23/SD_COPI: J16.DI/CMD, U1.37
ESP_23/SD_COPI1: J32.DI/CMD, U14.37
ESP_23/SD_COPI2: J50.DI/CMD, U21.37
ESP_25/SD_!CS!: J16.CS/DAT3, R13.1, U1.10
ESP_25/SD_!CS!1: J32.CS/DAT3, R54.1, U14.10
ESP_25/SD_!CS!2: J50.CS/DAT3, R84.1, U21.10
ESP_26/ZED_TX_READY: J18.1, R9.P8, U1.11
ESP_26/ZED_TX_READY1: J35.1, R39.P8, U14.11
ESP_26/ZED_TX_READY2: J53.1, R69.P8, U21.11
ESP_26/ZED_TX_READY_LV: R9.P1, U3.46
ESP_26/ZED_TX_READY_LV1: R39.P1, U8.46
ESP_26/ZED_TX_READY_LV2: R69.P1, U16.46
ESP_27/ZED_!RESET!: J18.2, R2.P5, U1.12, ZED_CONTROL.4
ESP_27/ZED_!RESET!1: J35.2, R40.P5, U14.12, ZED_CONTROL1.4
ESP_27/ZED_!RESET!2: J53.2, R70.P5, U21.12, ZED_CONTROL2.4
ESP_27/ZED_!RESET!_LV: R2.P4, U3.49
ESP_27/ZED_!RESET!_LV1: R40.P4, U8.49
ESP_27/ZED_!RESET!_LV2: R70.P4, U16.49
ESP_32/PWR_LVL_RED: D13.5, U1.8
ESP_32/PWR_LVL_RED1: D25.5, U14.8
ESP_32/PWR_LVL_RED2: D38.5, U21.8
ESP_33/PWR_LVL_GRN: D13.4, U1.9
ESP_33/PWR_LVL_GRN1: D25.4, U14.9
ESP_33/PWR_LVL_GRN2: D38.4, U21.9
ESP_36/BATT_ALRT: U1.4, U7.5
ESP_36/BATT_ALRT1: U11.5, U14.4
ESP_36/BATT_ALRT2: U18.5, U21.4
ESP_D1+: D2.3, J3.A6, J3.B6
ESP_D1+1: D24.3, J25.A6, J25.B6
ESP_D1+2: D37.3, J43.A6, J43.B6
ESP_D1-: D2.1, J3.A7, J3.B7
ESP_D1-1: D24.1, J25.A7, J25.B7
ESP_D1-2: D37.1, J43.A7, J43.B7
EXTERNAL_SERIAL1_RXI: SERIAL1_CONNECTION.4, ZED_CONTROL.6
EXTERNAL_SERIAL1_RXI1: SERIAL1_CONNECTION1.4, ZED_CONTROL1.6
EXTERNAL_SERIAL1_RXI2: SERIAL1_CONNECTION2.4, ZED_CONTROL2.6
EXTERNAL_SERIAL1_RXI/ZED_!RESET!: J2.3, J12.2, ZED_CONTROL.5
EXTERNAL_SERIAL1_RXI/ZED_!RESET!1: J27.3, J29.2, ZED_CONTROL1.5
EXTERNAL_SERIAL1_RXI/ZED_!RESET!2: J45.3, J47.2, ZED_CONTROL2.5
EXTERNAL_SERIAL1_TXO: DUAL_OUTPUT.2, SERIAL1_CONNECTION.1, ZED_CONTROL.3
EXTERNAL_SERIAL1_TXO1: DUAL_OUTPUT1.2, SERIAL1_CONNECTION1.1, ZED_CONTROL1.3
EXTERNAL_SERIAL1_TXO2: DUAL_OUTPUT2.2, SERIAL1_CONNECTION2.1, ZED_CONTROL2.3
EXTERNAL_SERIAL1_TXO/PPS: J2.2, J12.3, ZED_CONTROL.2
EXTERNAL_SERIAL1_TXO/PPS1: J27.2, J29.3, ZED_CONTROL1.2
EXTERNAL_SERIAL1_TXO/PPS2: J45.2, J47.3, ZED_CONTROL2.2
FENCE_LV: R4.P8, U3.19
FENCE_LV1: R53.P8, U8.19
FENCE_LV2: R83.P8, U16.19
GND: C1.2, C2.2, C4.2, C5.1, C6.2, C7.1, C8.2, C9.2, C10.2, C11.2, C12.2, C13.2, C14.2, C15.2, C16.2, C17.2, C18.2, D1.C, D2.2, D4.C, D6.2, D8.C, D10.C, D11.C, D12.C, D14.2, E1.GND@0, E1.GND@1, E1.GND@2, E1.GND@3, J1.1, J2.4, J3.GND, J3.GND2, J3.SHLD1, J3.SHLD2, J3.SHLD3, J3.SHLD4, J4.1, J5.GND, J5.GND2, J5.SHLD1, J5.SHLD2, J5.SHLD3, J5.SHLD4, J6.2, J8.1, J9.4, J10.2, J11.1, J12.1, J13.1, J14.2, J16.CD1, J16.GND, J16.GND1, J16.GND3, J17.1, R6.2, R7.1, R8.2, R15.1, R16.1, R17.1, R18.1, R30.1, R37.1, R38.1, U1.1, U1.15, U1.38, U1.GND1, U1.GNDT1, U1.GNDT2, U1.GNDT3, U1.GNDT4, U1.GNDT5, U1.GNDT6, U1.GNDT7, U1.GNDT8, U2.2, U3.1, U3.3, U3.12, U3.14, U3.32, U3.37, U3.41, U3.48, U3.55, U3.56, U3.57, U3.58, U3.59, U3.60, U3.61, U3.62, U3.63, U3.64, U3.65, U3.66, U3.67, U3.68, U3.69, U3.70, U3.71, U3.72, U3.73, U3.74, U3.75, U3.76, U3.77, U3.78, U3.79, U3.80, U3.81, U3.82, U3.83, U3.84, U3.85, U3.86, U3.87, U3.88, U3.89, U3.90, U3.91, U3.92, U3.93, U3.94, U3.95, U3.96, U3.97, U3.98, U3.99, U3.100, U3.101, U3.102, U4.2, U6.1, U7.1, U7.4, U7.6, U7.9, U10.5, U10.11
GND1: C3.2, C19.1, C20.2, C21.2, C22.2, C23.1, C24.2, C25.2, C26.2, C27.2, C28.2, C29.2, C30.2, C31.2, C32.2, C33.2, C34.2, D5.C, D16.2, D17.C, D19.C, D20.C, D21.C, D22.C, D24.2, D26.2, E2.GND@0, E2.GND@1, E2.GND@2, E2.GND@3, J19.1, J20.GND, J20.GND2, J20.SHLD1, J20.SHLD2, J20.SHLD3, J20.SHLD4, J22.1, J23.2, J24.2, J25.GND, J25.GND2, J25.SHLD1, J25.SHLD2, J25.SHLD3, J25.SHLD4, J26.4, J27.4, J28.1, J29.1, J30.1, J32.CD1, J32.GND, J32.GND1, J32.GND3, J33.2, J34.1, J36.1, R33.1, R35.1, R36.1, R43.1, R50.1, R51.1, R56.2, R57.2, R58.1, R60.1, U5.2, U8.1, U8.3, U8.12, U8.14, U8.32, U8.37, U8.41, U8.48, U8.55, U8.56, U8.57, U8.58, U8.59, U8.60, U8.61, U8.62, U8.63, U8.64, U8.65, U8.66, U8.67, U8.68, U8.69, U8.70, U8.71, U8.72, U8.73, U8.74, U8.75, U8.76, U8.77, U8.78, U8.79, U8.80, U8.81, U8.82, U8.83, U8.84, U8.85, U8.86, U8.87, U8.88, U8.89, U8.90, U8.91, U8.92, U8.93, U8.94, U8.95, U8.96, U8.97, U8.98, U8.99, U8.100, U8.101, U8.102, U9.1, U11.1, U11.4, U11.6, U11.9, U12.2, U13.5, U13.11, U14.1, U14.15, U14.38, U14.GND1, U14.GNDT1, U14.GNDT2, U14.GNDT3, U14.GNDT4, U14.GNDT5, U14.GNDT6, U14.GNDT7, U14.GNDT8
GND2: C35.2, C36.1, C37.2, C38.2, C39.2, C40.1, C41.2, C42.2, C43.2, C44.2, C45.2, C46.2, C47.2, C48.2, C49.2, C50.2, C51.2, D27.C, D29.2, D30.C, D32.C, D33.C, D34.C, D35.C, D37.2, D39.2, E3.GND@0, E3.GND@1, E3.GND@2, E3.GND@3, J37.1, J38.GND, J38.GND2, J38.SHLD1, J38.SHLD2, J38.SHLD3, J38.SHLD4, J40.1, J41.2, J42.2, J43.GND, J43.GND2, J43.SHLD1, J43.SHLD2, J43.SHLD3, J43.SHLD4, J44.4, J45.4, J46.1, J47.1, J48.1, J50.CD1, J50.GND, J50.GND1, J50.GND3, J51.2, J52.1, J54.1, R66.1, R67.1, R68.1, R73.1, R80.1, R81.1, R86.2, R87.2, R88.1, R90.1, U15.2, U16.1, U16.3, U16.12, U16.14, U16.32, U16.37, U16.41, U16.48, U16.55, U16.56, U16.57, U16.58, U16.59, U16.60, U16.61, U16.62, U16.63, U16.64, U16.65, U16.66, U16.67, U16.68, U16.69, U16.70, U16.71, U16.72, U16.73, U16.74, U16.75, U16.76, U16.77, U16.78, U16.79, U16.80, U16.81, U16.82, U16.83, U16.84, U16.85, U16.86, U16.87, U16.88, U16.89, U16.90, U16.91, U16.92, U16.93, U16.94, U16.95, U16.96, U16.97, U16.98, U16.99, U16.100, U16.101, U16.102, U17.1, U18.1, U18.4, U18.6, U18.9, U19.2, U20.5, U20.11, U21.1, U21.15, U21.38, U21.GND1, U21.GNDT1, U21.GNDT2, U21.GNDT3, U21.GNDT4, U21.GNDT5, U21.GNDT6, U21.GNDT7, U21.GNDT8
GPS_ANT1: D14.1, E1.SIG, FB1.1, U3.2
GPS_ANT2: D26.1, E2.SIG, FB2.1, U8.2
GPS_ANT3: D39.1, E3.SIG, FB3.1, U16.2
LIPO_RAW: J8.2, MEAS1.1, MEAS1.3
LIPO_RAW1: J22.2, MEAS3.1, MEAS3.3
LIPO_RAW2: J40.2, MEAS5.1, MEAS5.3
unnamed: D3.A, R12.1
unnamed: D1.A, R11.1
unnamed: D4.A, R10.2
unnamed: J5.VBUS1, J5.VBUS2, MEAS.1, MEAS.3
unnamed: R5.1, U10.8
unnamed: D13.1, R1.1
unnamed: D13.3, R6.1
unnamed: D13.2, R8.1
unnamed: D5.A, R19.1
unnamed: R21.2, U8.40
unnamed: R27.2, U3.40
unnamed: R28.2, U3.39
unnamed: R14.2, U3.7
unnamed: R22.2, U8.39
unnamed: D15.A, R31.1
unnamed: R32.2, U8.7
unnamed: D17.A, R42.2
unnamed: D19.A, R44.2
unnamed: D20.A, R45.2
unnamed: D21.A, R46.2
unnamed: Q1.5, R48.2
unnamed: Q1.2, R49.2
unnamed: D23.A, J25.VBUS1, J25.VBUS2
unnamed: Q2.5, R23.2
unnamed: Q2.2, R29.2
unnamed: D8.A, R24.2
unnamed: D10.A, R25.2
unnamed: D22.A, R52.2
unnamed: D11.A, R26.2
unnamed: D12.A, R34.2
unnamed: J20.VBUS1, J20.VBUS2, MEAS2.1, MEAS2.3
unnamed: D9.A, J3.VBUS1, J3.VBUS2
unnamed: R59.1, U13.8
unnamed: D25.1, R55.1
unnamed: D25.3, R56.1
unnamed: D25.2, R57.1
unnamed: D27.A, R61.1
unnamed: R62.2, U16.40
unnamed: R63.2, U16.39
unnamed: D28.A, R64.1
unnamed: R65.2, U16.7
unnamed: D30.A, R72.2
unnamed: D32.A, R74.2
unnamed: D33.A, R75.2
unnamed: D34.A, R76.2
unnamed: Q3.5, R78.2
unnamed: Q3.2, R79.2
unnamed: D36.A, J43.VBUS1, J43.VBUS2
unnamed: D35.A, R82.2
unnamed: J38.VBUS1, J38.VBUS2, MEAS4.1, MEAS4.3
unnamed: R89.1, U20.8
unnamed: D38.1, R85.1
unnamed: D38.3, R86.1
unnamed: D38.2, R87.1
NMEA-RX: BLUETOOTH_BROADCAST.6, SERIAL1_CONNECTION.6
NMEA-RX1: BLUETOOTH_BROADCAST1.6, SERIAL1_CONNECTION1.6
NMEA-RX2: BLUETOOTH_BROADCAST2.6, SERIAL1_CONNECTION2.6
NMEA-TX: BLUETOOTH_BROADCAST.3, DUAL_OUTPUT.1, SERIAL1_CONNECTION.3
NMEA-TX1: BLUETOOTH_BROADCAST1.3, DUAL_OUTPUT1.1, SERIAL1_CONNECTION1.3
NMEA-TX2: BLUETOOTH_BROADCAST2.3, DUAL_OUTPUT2.1, SERIAL1_CONNECTION2.3
PPS: R2.P1, U3.53
PPS1: R40.P1, U8.53
PPS2: R70.P1, U16.53
PROG1: R7.2, U10.6
PROG2: R43.2, U13.6
PROG3: R73.2, U20.6
RTK_LV: R4.P7, U3.20
RTK_LV1: R53.P7, U8.20
RTK_LV2: R83.P7, U16.20
RX2_LV: R4.P6, U3.26
RX2_LV1: R53.P6, U8.26
RX2_LV2: R83.P6, U16.26
RXLV: R9.P4, U3.43
RXLV1: R39.P4, U8.43
RXLV2: R69.P4, U16.43
SCL_LV: R9.P2, U3.45
SCL_LV1: R39.P2, U8.45
SCL_LV2: R69.P2, U16.45
SDA_LV: R9.P3, U3.44
SDA_LV1: R39.P3, U8.44
SDA_LV2: R69.P3, U16.44
TX2_LV: R4.P5, U3.27
TX2_LV1: R53.P5, U8.27
TX2_LV2: R83.P5, U16.27
TXLV: R3.1, U3.42
TXLV1: R41.1, U8.42
TXLV2: R71.1, U16.42
UNP_D+: D6.3, J5.A6, J5.B6
UNP_D+1: D16.3, J20.A6, J20.B6
UNP_D+2: D29.3, J38.A6, J38.B6
UNP_D-: D6.1, J5.A7, J5.B7
UNP_D-1: D16.1, J20.A7, J20.B7
UNP_D-2: D29.1, J38.A7, J38.B7
VIN: C9.1, D2.5, D6.5, D7.C, D9.C, D13.6, J7.2, MEAS.2, MEAS.4, U10.1, U10.2
VIN1: C25.1, D16.5, D18.C, D23.C, D24.5, D25.6, J21.2, MEAS2.2, MEAS2.4, U13.1, U13.2
VIN2: C42.1, D29.5, D31.C, D36.C, D37.5, D38.6, J39.2, MEAS4.2, MEAS4.4, U20.1, U20.2
V_BATT: C8.1, C15.1, C17.1, D7.A, J10.1, MEAS1.2, MEAS1.4, U4.1, U4.3, U7.2, U7.3, U10.9, U10.10
V_BATT1: C24.1, C32.1, C33.1, D18.A, J23.1, MEAS3.2, MEAS3.4, U11.2, U11.3, U12.1, U12.3, U13.9, U13.10
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

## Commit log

2021-07-01 Replace SMA SMD with edge mount SMA. v17 PCB
    [SparkFun GPS RTK Surveyor.brd, SparkFun GPS RTK Surveyor.sch]
2021-07-01 Update panel to v17
    [SparkFun GPS RTK Surveyor-Panel.GBL, SparkFun GPS RTK Surveyor-Panel.GBO, SparkFun GPS RTK Surveyor-Panel.GBS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]
2022-03-30 Add route out note
    [SparkFun GPS RTK Surveyor.brd, SparkFun GPS RTK Surveyor.sch]

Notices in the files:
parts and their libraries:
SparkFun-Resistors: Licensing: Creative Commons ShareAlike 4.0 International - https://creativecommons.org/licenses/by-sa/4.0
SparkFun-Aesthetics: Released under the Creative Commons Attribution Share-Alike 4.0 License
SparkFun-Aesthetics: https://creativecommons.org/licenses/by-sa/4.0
